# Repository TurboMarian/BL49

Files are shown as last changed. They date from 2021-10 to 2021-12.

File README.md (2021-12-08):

# BL49
Wideband Lambda Controller with Bosch CJ125 and LSU 4.9 with 0-5V output and CAN-Bus Interface<br/>

### Suitable Bosch lambda probes: ###
|Bosch number  |Length overall|Comment|
|---|---|---|
|0 258 017 025 |1000mm|Bosch motorsport part|
|0 258 017 012 |1060mm||
|0 281 004 184 |1000mm||
|0 281 004 150 |1215mm||
|0 258 017 126 |680mm|black, used by BMW after 09/2006 (1178 7561410)|
|0 258 017 029 |620mm|grey, used by BMW after 09/2006 (1178 7539124)|
|0 258 017 092 |950mm|black, used by BMW (1178 7540167)|
|0 258 017 038 |340mm|grey, used by BMW (11787537984)|
|...|||

**Probe pinout:**
|Pin#|Color|Description|Symbol|
|----|-----|---|---|
|1|red|Pump current APE|IP|
|2|yellow|Virtual ground IPN|VM|
|3|white|Heater voltage H-|Uh-|
|4|grey|Heater voltaget H+|Uh+|
|5|green|Trim Resistor RT|IA|
|6|black|Nernst voltage UN|RE|

**Ua and Ur during calibration (cold sensor, 10 calibration samples with 10ms pause):**
- Ua: 359 => 1,7529V (should be 1.5V in calibration mode!)
- Ur: 337 => 1.6455V

**Changes:**
- 29.04.2020 - Version 0.0.1 -hardware released / software still in development, needs some changes in hardware<br/>
- 27.11.2021 - Version 0.0.3 - hardware in development, some modifications in analog PSU / software for V0.0.1 can be used with this<br/>

Interactive BOM for easier hand-soldering you can download from the github (BL49/hardware/V0.0.1/bom)
or access online here: https://oelprinz.000webhostapp.com/BL49/V0.0.1/iBOM/ibom.html <br/>
Quick link to schematic: https://github.com/oelprinz-org/BL49/blob/master/hardware/V0.0.1/schematics.pdf <br/>
Assembled Prototype
<p align="center">
  Top Side
  accessibility text<br/>
    Top Side
  accessibility text
</p>

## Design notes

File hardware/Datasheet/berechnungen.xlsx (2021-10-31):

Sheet: PWM
Fcpu | 16000000
Prescaler | 64 | 1, 8, 64, 256 and 1024 are valid
Resolution, bit | 10
TOP | 1023
Fpwm | 244.140625
Ubat, V | 13.6
condens, V | 1.5
duty, % | 11.02941176
dutyCycle | 112.9411765

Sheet: ADC
Referenz, V | 5
ADC Wert | 563 | 566
ADC-Spannung, V | 2.749023438
Spannungsteiler | 4.9 | Gesamtwiderstand / Massenwiderstand
echte Spannung, V | 13.47021484
echte Spannung, V | 13
ADC-Spannung, V | 2.653061224
ADC-Wert | 543.3469388

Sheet: LSU 4.9 Pinout
Pin# | Color | Description | Function
1 | red | Pump current APE | IP
2 | yellow | Virtual groun | VM
3 | white | Heater voltage H- | Uh-
4 | grey | Heater voltage H+ | Uh+
5 | green | Trim resistor | IA
6 | black | Nernst voltage | UN

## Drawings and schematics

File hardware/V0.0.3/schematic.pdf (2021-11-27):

A

A

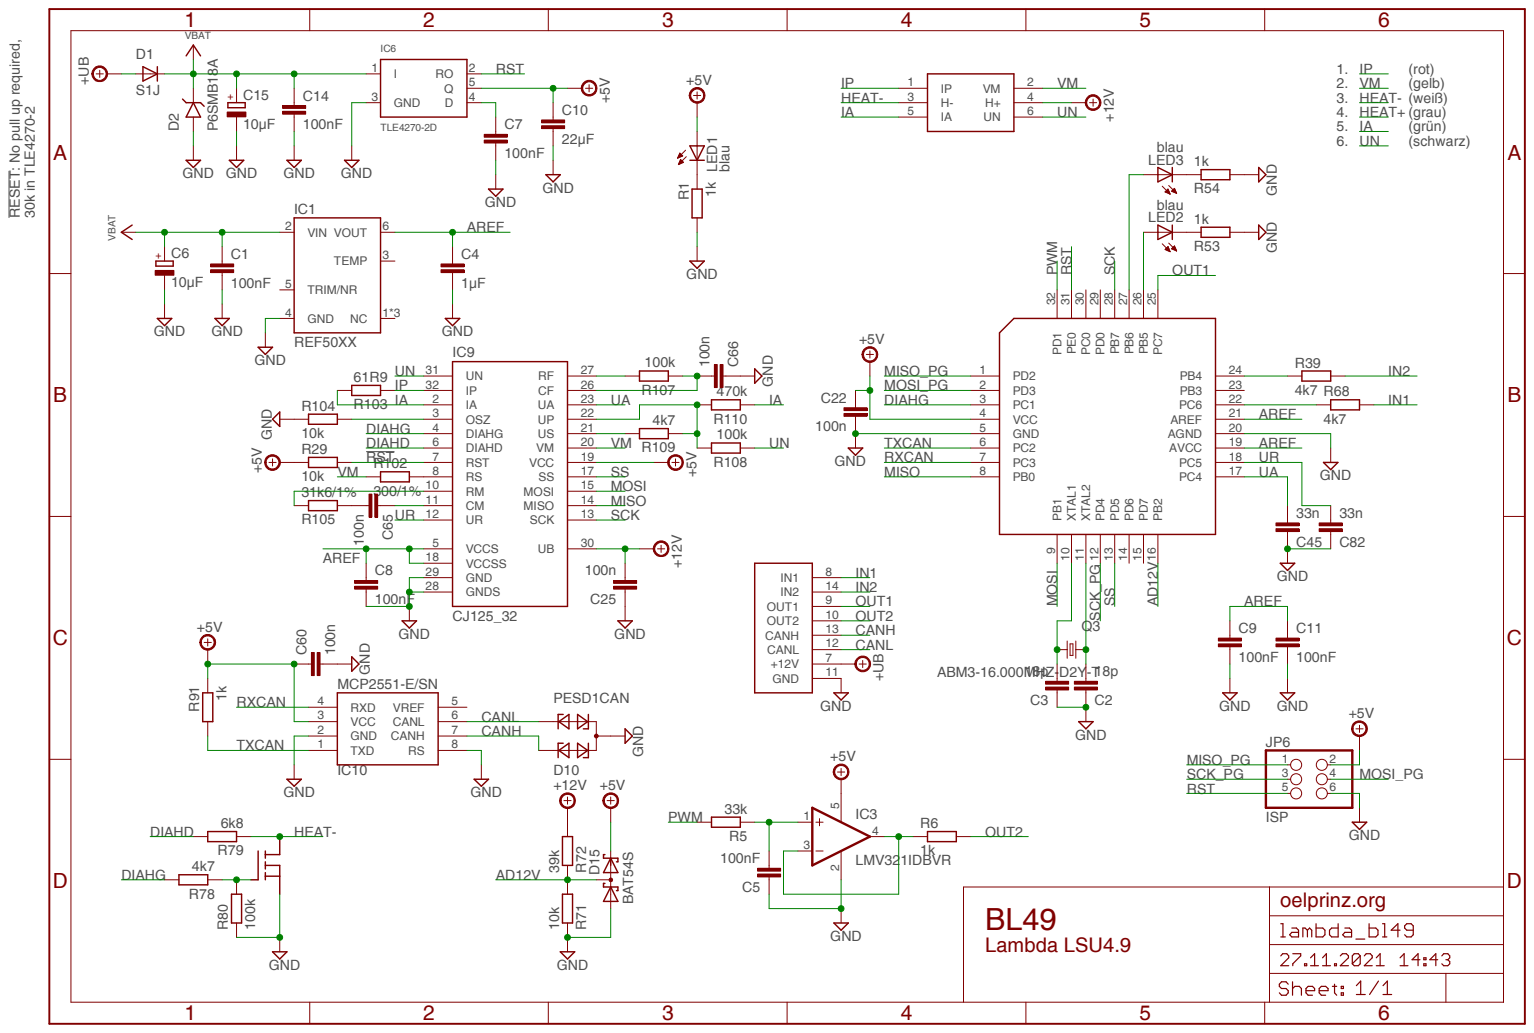
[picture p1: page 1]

RESET: No pull up required,

5 | SCK

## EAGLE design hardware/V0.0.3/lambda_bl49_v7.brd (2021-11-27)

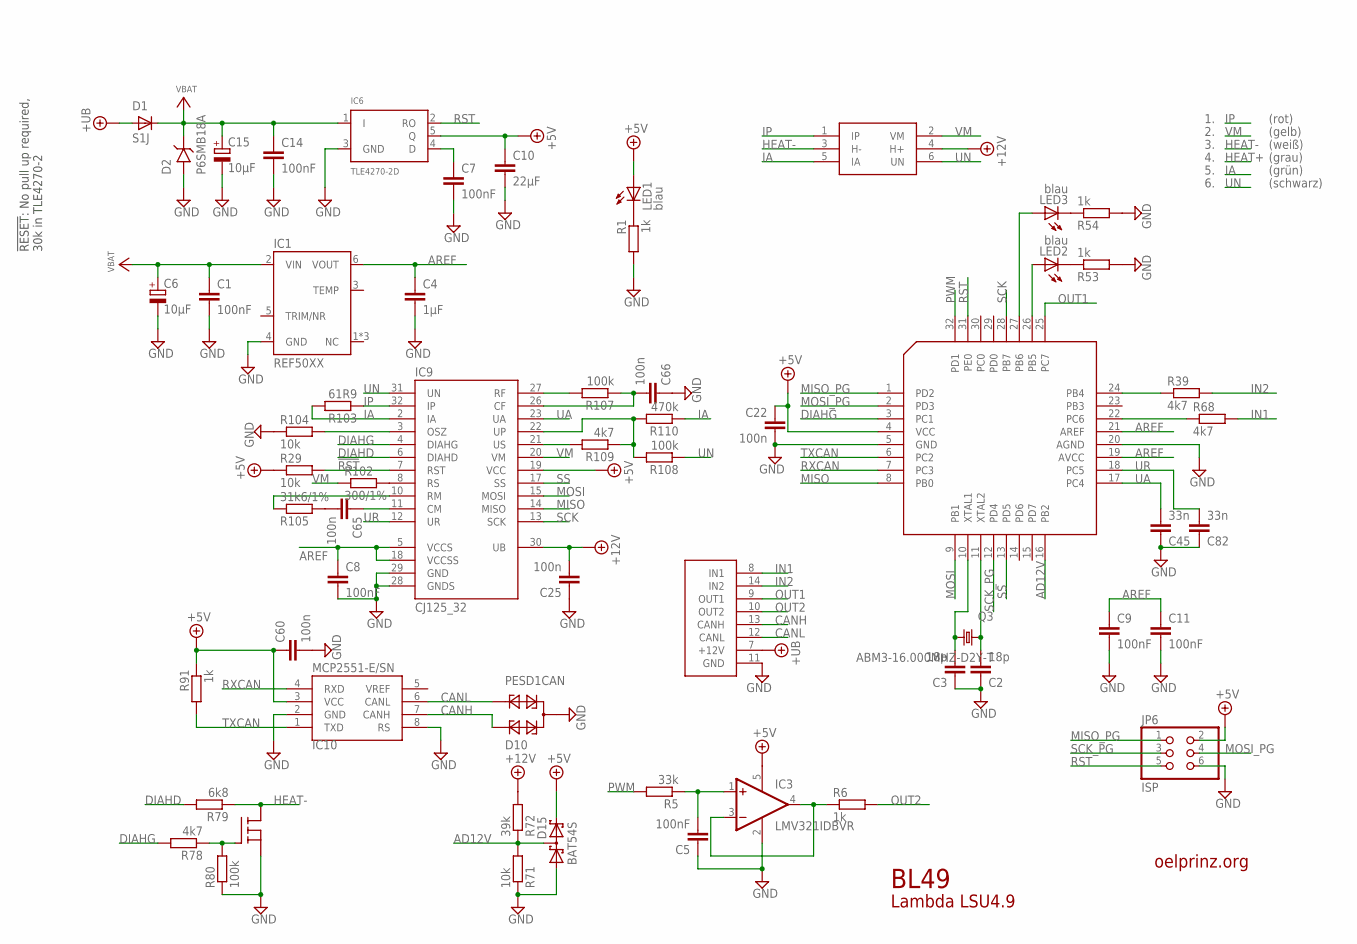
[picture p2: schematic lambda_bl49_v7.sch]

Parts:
C1, C5, C7, C8, C9, C11, C14: 100nF; C0603
C2, C3: 18p; C0603
C4: 1µF; C0603
C6, C15: 10µF; PANASONIC_D
C10: 22µF; C1206
C22, C25, C60, C65, C66: 100n; C0603
C45, C82: 33n; C0603
D1: S1J; SMADIODE
D2: P6SMB18A; DO-214AA
D10: PESD1CAN; SOT23
D15: BAT54S; SOT23
IC1: REF50XX; SOIC127P600X175-8N
IC3: LMV321IDBVR; SC70-5L
IC6: TLE4270-2D; TO252-51
IC9: CJ125_32; TQFP32-08
IC10: MCP2551-E/SN; SOIC8
JP6: ISP; 2X03
LED1, LED2, LED3: blau; SML0805
Q3: ABM3-16.000MHZ-D2Y-T; ABM3
R1, R6, R53, R54, R91: 1k; R0603
R5: 33k; R0603
R29, R71, R104: 10k; R0603
R39, R68, R78, R109: 4k7; R0603
R72: 39k; R0603
R79: 6k8; R0603
R80, R107, R108: 100k; R0603
R102: 300/1%; R0603
R103: 61R9; R0603
R105: 31k6/1%; R0603
R110: 470k; R0603
U$1: BL49
U$2: ATMEGA32M1-AU; TQFP32-08
U$3: STD30NF06LT4; DPACK_2

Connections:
!RST: IC9.7 (RST), R29.2
+5V: C10.1, C22.1, C60.1, D15.2 (C2), IC3.5 (V+), IC6.5 (Q), IC9.19 (VCC), IC10.3 (VCC), JP6.2, LED1.A, R29.1, R91.1, U$2.4 (VCC)
+12V: C25.2, IC9.30 (UB), R72.2, U$1.4 (H+)
+UB: D1.A, U$1.7 (+12V)
AD12V: D15.3 (C1A2), R71.2, R72.1, U$2.16 (PB2)
AREF: C4.1, C8.1, C9.1, C11.1, IC1.6 (VOUT), IC9.5 (VCCS), IC9.18 (VCCSS), U$2.19 (AVCC), U$2.21 (AREF)
CANH: D10.1, IC10.7 (CANH), U$1.13 (CANH)
CANL: D10.2, IC10.6 (CANL), U$1.12 (CANL)
DIAHD: IC9.6 (DIAHD), R79.2
DIAHG: IC9.4 (DIAHG), R78.2, U$2.3 (PC1)
GND: C1.2, C2.1, C3.1, C4.2, C5.1, C6.-, C7.2, C8.2, C9.2, C10.2, C11.2, C14.2, C15.-, C22.2, C25.1, C45.1, C60.2, C66.1, C82.1, D2.P$2 (A), D10.3, D15.1 (A1), IC1.4 (GND), IC3.2 (V-), IC6.3 (GND), IC9.28 (GNDS), IC9.29 (GND), IC10.2 (GND), IC10.8 (RS), JP6.6, R1.2, R53.2, R54.2, R71.1, R80.1, R104.1, U$1.11 (GND), U$2.5 (GND), U$2.20 (AGND), U$3.S (3)
HEAT-: R79.1, U$1.3 (H-), U$3.D (2)
IA: IC9.2 (IA), R103.2, R110.1, U$1.5 (IA)
IN1: R68.2, U$1.8 (IN1)
IN2: R39.2, U$1.14 (IN2)
IP: IC9.32 (IP), R103.1, U$1.1 (IP)
MISO: IC9.14 (MISO), U$2.8 (PB0)
MISO_PG: JP6.1, U$2.1 (PD2)
MOSI: IC9.15 (MOSI), U$2.9 (PB1)
MOSI_PG: JP6.4, U$2.2 (PD3)
unnamed: IC9.3 (OSZ), R104.2
unnamed: LED1.C, R1.1
unnamed: C7.1, IC6.4 (D)
unnamed: IC9.10 (RM), R105.1
unnamed: C5.2, IC3.1 (+IN), R5.1
unnamed: IC3.3 (-IN), IC3.4 (OUT), R6.1
unnamed: C2.2, Q3.1, U$2.11 (XTAL2)
unnamed: C65.1, IC9.11 (CM)
unnamed: C3.2, Q3.2, U$2.10 (XTAL1)
unnamed: C65.2, R105.2
unnamed: IC9.8 (RS), R102.2
unnamed: R39.1, U$2.24 (PB4)
unnamed: LED2.A, U$2.26 (PB5)
unnamed: LED2.C, R53.1
unnamed: LED3.C, R54.1
unnamed: LED3.A, U$2.27 (PB6)
unnamed: R68.1, U$2.22 (PC6)
unnamed: IC9.27 (RF), R107.2
unnamed: IC9.22 (UP), R108.2, R109.1, R110.2
unnamed: IC9.21 (US), R109.2
unnamed: R78.1, R80.2, U$3.G (1)
unnamed: C66.2, IC9.26 (CF), R107.1
OUT1: U$1.9 (OUT1), U$2.25 (PC7)
OUT2: R6.2, U$1.10 (OUT2)
PWM: R5.2, U$2.32 (PD1)
RST: IC6.2 (RO), JP6.5, U$2.31 (PE0)
RXCAN: IC10.4 (RXD), U$2.7 (PC3)
SCK: IC9.13 (SCK), U$2.28 (PB7)
SCK_PG: JP6.3, U$2.12 (PD4)
SS: IC9.17 (SS), U$2.13 (PD5)
TXCAN: IC10.1 (TXD), R91.2, U$2.6 (PC2)
UA: C45.2, IC9.23 (UA), U$2.17 (PC4)
UN: IC9.31 (UN), R108.1, U$1.6 (UN)
UR: C82.2, IC9.12 (UR), U$2.18 (PC5)
VBAT: C1.1, C6.+, C14.1, C15.+, D1.C, D2.P$1 (C), IC1.2 (VIN), IC6.1 (I)
VM: IC9.20 (VM), R102.1, U$1.2 (VM)

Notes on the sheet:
Lambda LSU4.9
oelprinz.org
BL49
(grau)
(weiß)
(gelb)
(grün)
(rot)
(schwarz)
!RESET!: No pull up required, 30k in TLE4270-2

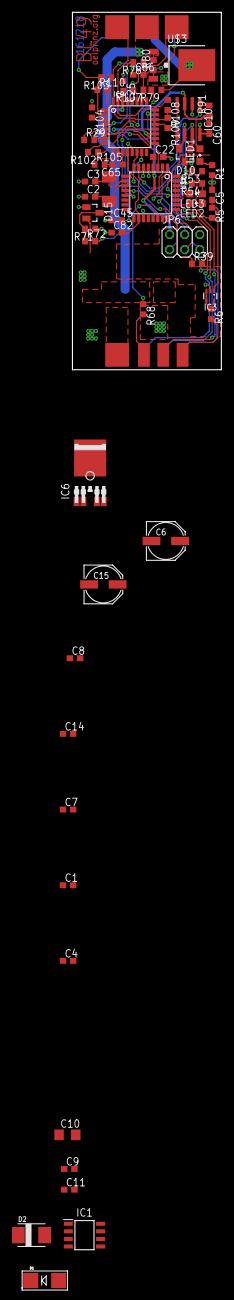
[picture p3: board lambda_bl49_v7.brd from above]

Board: 2 copper layers, 25.0 x 60.0 mm, 59 parts (0 on the bottom side), 56 nets.

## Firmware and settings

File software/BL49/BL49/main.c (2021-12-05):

/*
 * BL49.c
 *
 * Created: 16.10.2021 23:06:12
 * Author : Heinrich
 */ 

#include <avr/io.h>
#include <avr/interrupt.h>
#include <stdint.h>
#include <stdbool.h>
#include "adc/adc.h"
#include "dac/dac.h"
#include "can/can_lib.h"
#include "timer/timer.h"
#include "spi/spi.h"
#include "pwm/pwm.h"
#include "chip/chip.h"
#include "chip/gpio.h"
#include "cj125/cj125.h"
#include "cj125/cj125_register.h"
#include "probe/probe.h"

#include "config.h"
#include "helpers.h"

int main(void)
{
	chip_init();
	can_init(1);
	timer_delay_ms(50);
	adc_init();
	dac_init();
	spi_init();
	pwm_init();
	sei();
	
	uint16_t cj125_diag;
	uint16_t pwm_duty = 0;
	uint16_t timer_value = 0;
	uint16_t heater_voltage = 0;
	int counter = 0;
	
   	uint8_t pt_data[CAN_DLC];
	st_cmd_t msg;
	msg.id.ext = CAN_ID;
	msg.dlc = CAN_DLC;
	msg.cmd = CMD_TX_DATA;
	
	// check cj125 diag register after start, if all clear go to INIT:
	switch (cj125_diag = cj125_read_diag())
	{
		case CJ125_DIAG_REG_STATUS_OK:
			state = INIT;
		break;
		
		case CJ125_DIAG_REG_STATUS_NOSENSOR:
			state = NO_PROBE;
		break;
		
		case CJ125_DIAG_REG_STATUS_NOPOWER:
			state = ERROR;
		break;
	}
			
    while (1) 
    {
		gpio_read_inputs(&inputs);
		
		switch (state)
		{
			case INIT:
				state = CALIBRATE;
			break;
			
			case WAIT_FOR_START:
			break;
			
			
			case CALIBRATE:
				counter = 0;
				cj125_set_calibration_mode();
				while (counter < CJ125_CALIBRATION_SAMPLE_COUNT)
				{
					inputs.UA_calibration += (adc_ua() + inputs.UOffset);
					inputs.UR_calibration += (adc_ur() + inputs.UOffset);
					timer_delay_ms(10);
					counter++;
				}
				
				inputs.UA_calibration /= CJ125_CALIBRATION_SAMPLE_COUNT;
				inputs.UR_calibration /= CJ125_CALIBRATION_SAMPLE_COUNT;
				
				// go to normal mode, ampl. 8x
				cj125_end_calibration_mode_v8();
				
				state = CONDENSATE;
				
			break;
			
			case CONDENSATE:
				// heating the probe on 1.5v for 5 seconds
				heater_voltage = 1500;
				pwm_duty = calculate_pwm_for_voltage(heater_voltage);
				pwm_set_duty(pwm_duty);
				pt_data[4] = (uint8_t)((uint32_t)(inputs.UBat + inputs.UOffset)* 245UL / 1024UL);
				pt_data[5] = 15;
				pt_data[6] = (1 << 1);	// bosch lsu4.9
				pt_data[7] = 0xf;	// evap startup
				
				// stay for 5 seconds in this case and send every 10ms a can message
				for (int i = 0; i <= 500; i++)
				{
					while(can_cmd(&msg) != CAN_CMD_ACCEPTED); // wait for MOb to configure
					while(can_get_status(&msg) == CAN_STATUS_NOT_COMPLETED); // wait for a transmit request to come in, and send a response
					timer_delay_ms(10);					
				}
				
				state = PREHEATING;
				
			break;
			
			case PREHEATING:
				// bring the probe on temperature, start at 8v and go up to 13v with 0.4v/sec
				heater_voltage = 8000;
				gpio_read_inputs(&inputs);
				pwm_duty = calculate_pwm_for_voltage(heater_voltage);
				// pwm_set_duty(pwm_duty);
			
				pt_data[4] = (uint8_t)((uint32_t)(inputs.UBat + inputs.UOffset)* 245UL / 1024UL);
				pt_data[6] = (1 << 1);	// bosch lsu4.9
				pt_data[7] = 0x1;	// warm up
				
				while (heater_voltage < 13000)
				{
					
					// increate heater voltage every second
					if (timer_value != 0 && timer_value % 1000 == 0)
					{
						heater_voltage += 400;
						gpio_read_inputs(&inputs);
						// limit heater voltage to 13v
						if (heater_voltage > 13000) heater_voltage = 13000;
						pwm_duty = calculate_pwm_for_voltage(heater_voltage);
						// pwm_set_duty(pwm_duty);
					}
					
					pt_data[5] = (uint8_t)((float) heater_voltage *0.01f);
					timer_delay_ms(10);
					timer_value += 10;
					
					while(can_cmd(&msg) != CAN_CMD_ACCEPTED); // wait for MOb to configure
					while(can_get_status(&msg) == CAN_STATUS_NOT_COMPLETED); // wait for a transmit request to come in, and send a response
				}
				
				// preheating done, go to run
				state = RUNNING;
			
			break;
			
			case RUNNING:
			// TODO: PID
			
			break;
			
			
			case ERROR:
			case NO_PROBE:
			
				pwm_duty = 10;
			
			break;
			
		}
		/*
		while(can_cmd(&msg) != CAN_CMD_ACCEPTED); // wait for MOb to configure
		while(can_get_status(&msg) == CAN_STATUS_NOT_COMPLETED); // wait for a transmit request to come in, and send a response
		dac_value(1080);
		LED2_TOG;
		timer_delay_ms(10);
		*/
		
		// LED2_TOG;
		/*
		retVal = cj125_read_ident();
		
		retVal = cj125_read_diag();
		
		power_ok = is_ubat_ok();
		
		timer_delay_ms(200);
		*/
	}
   
}

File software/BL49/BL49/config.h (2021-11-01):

/*
 * config.h
 *
 * Created: 16.10.2021 15:10:09
 *  Author: Heinrich
 */ 


#ifndef CONFIG_H_
#define CONFIG_H_

#include <avr/io.h>
#include <avr/interrupt.h>

#ifndef F_CPU
#warning "F_CPU war noch nicht definiert, wird nun mit 16MHz definiert"
#define F_CPU 16000000     /* Quarz mit 16 Mhz */
#endif

#ifndef FOSC
#warning "FOSC war noch nicht definiert, wird nun mit F_CPU/1000 definiert"
#define FOSC	F_CPU/1000
#endif

#ifndef CAN_BAUDRATE
#warning "CAN_BAUDRATE war noch nicht definiert, wird nun mit 500kbit definiert"
#define CAN_BAUDRATE	500
#endif

#define CAN_ID		0x180
#define CAN_DLC		8

// leds
#define LEDS			DDRB
#define LEDS_PORT		PORTB
#define CPC1017			PB3
#define LED2			PB5
#define LED3			PB6
#define CPC1017_ON		(LEDS_PORT |= (1 << CPC1017))
#define CPC1017_OFF		(LEDS_PORT &= ~(1 << CPC1017))
#define LED2_ON			(LEDS_PORT |= (1 << LED2))
#define LED2_OFF		(LEDS_PORT &= ~(1 << LED2))
#define LED2_TOG		(LEDS_PORT ^= (1 << LED2))
#define LED3_ON			(LEDS_PORT |= (1 << LED3))
#define LED3_OFF		(LEDS_PORT &= ~(1 << LED3))
#define LED3_TOG		(LEDS_PORT ^= (1 << LED3))

// spi
#define SPI_MOSI		PB1
#define SPI_SCK			PB7
#define SPI_SS			PD5
#define SPI_SS_SELECT	(PORTD &= ~(1 << SPI_SS))
#define SPI_SS_DESELECT	(PORTD |= (1 << SPI_SS))

// checks for adc
#define UBat_MIN		0x01C4	// 10,8V; 0x01C4 => 452 => 10,81V
#define UBat_MAX		0x02B0	// 16,5V; 0x02B0 => 688 => 16,46V

// heater
#define	HEATER_PIN		PC1
#define HEATER_PORT		PORTC
#define HEATER_ON		(HEATER_PORT &= ~(1 << HEATER_PIN))
#define HEATER_OFF		(HEATER_PORT |= (1 << HEATER_PIN))
#define HEATER_TOG		(HEATER_PORT ^= (1 << HEATER_PIN))
#define HEATER_MAX_V	0x021F	// 13V

#endif /* CONFIG_H_ */

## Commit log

2021-10-19 some adc functions added
2021-10-27 dac stuff added, spi stuff added
2021-10-28 pwm stuff added
    [berechnungen.xlsx]
2021-10-28 spi implemented, adc corrected, some pins/ports corrected, cj125 basic communication implemented
    [berechnungen.xlsx]
2021-10-29 adc input reading corrected
    [berechnungen.xlsx]
2021-10-29 adc and pwm corrected
    [gpio.c, main.c]
2021-10-31 -> new datasheet added -> start pwm duty set to 0 -> lsu 4.9 pin out added
    [berechnungen.xlsx]
2021-10-31 Update README.md
    Bosch probe number and pinout added
2021-11-01 added schematic of my pcb... added probe condensing and preheating
2021-11-12 revision V0.0.3 created and added some datasheets
    [lambda_bl49.brd, lambda_bl49.sch]
2021-11-13 eagle v7 schematic added
    [lambda_bl49_v7.brd, lambda_bl49_v7.sch]
2021-11-27 tls115 replaced by ti ref5050
    [lambda_bl49.brd, lambda_bl49.sch, lambda_bl49_v7.brd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]
2021-12-05 pid added
2021-12-06 bosch probe list added

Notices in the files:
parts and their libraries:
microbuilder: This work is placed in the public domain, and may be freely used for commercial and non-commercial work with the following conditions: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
